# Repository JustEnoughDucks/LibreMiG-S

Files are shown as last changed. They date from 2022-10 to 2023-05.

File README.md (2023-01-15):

# LibreMiG-S

<!-- Improved compatibility of back to top link: See: https://github.com/othneildrew/Best-README-Template/pull/73 -->

<!--
*** Thanks for checking out the Best-README-Template. If you have a suggestion
*** that would make this better, please fork the repo and create a pull request
*** or simply open an issue with the tag "enhancement".
*** Don't forget to give the project a star!
*** Thanks again! Now go create something AMAZING! :D
-->

<!-- PROJECT SHIELDS -->
<!--
*** I'm using markdown "reference style" links for readability.
*** Reference links are enclosed in brackets [ ] instead of parentheses ( ).
*** See the bottom of this document for the declaration of the reference variables
*** for contributors-url, forks-url, etc. This is an optional, concise syntax you may use.
*** https://www.markdownguide.org/basic-syntax/#reference-style-links
-->
[][contributors-url]
[][forks-url]
[][stars-url]
[][issues-url]
[][license-url]
<!-- [![LinkedIn][linkedin-shield]][linkedin-url] -->

<!-- PROJECT LOGO -->
<br />
<div align="center">
  <a href="https://github.com/JustEnoughDucks/LibreMiG-S">
    
  </a>

  <h3 align="center">LibreMiG-S</h3>

  <p align="center">
    Open Source Joystick/Open Source Flightstick that combines the Olukelu Gimbal with a MiG-31 inspired Flightstick designed for Star Citizen or space simulators
    <!-- <br />
    <a href="https://github.com/JustEnoughDucks/LibreMiG-S"><strong>Explore the docs »</strong></a>
    <br /> -->
    <br /> 
    <a href="https://github.com/JustEnoughDucks/LibreMiG-S">View Demo</a>
    ·
    <a href="https://github.com/JustEnoughDucks/LibreMiG-S/issues">Report Bug</a>
    ·
    <a href="https://github.com/JustEnoughDucks/LibreMiG-S/issues">Request Feature</a>
  </p>
</div>

<!-- TABLE OF CONTENTS -->
<details>
  <summary>Table of Contents</summary>
  <ol>
    <li>
      <a href="#about-the-project">About The Project</a>
      <ul>
        <li><a href="#built-with">Built With</a></li>
      </ul>
    </li>
    <li>
      <a href="#getting-started">Getting Started</a>
      <ul>
        <li><a href="#prerequisites">Prerequisites</a></li>
        <li><a href="#installation">Installation</a></li>
      </ul>
    </li>
    <li><a href="#usage">Usage</a></li>
    <li><a href="#roadmap">Roadmap</a></li>
    <li><a href="#contributing">Contributing</a></li>
    <li><a href="#license">License</a></li>
    <li><a href="#contact">Contact</a></li>
    <li><a href="#acknowledgments">Acknowledgments</a></li>
  </ol>
</details>

<!-- ABOUT THE PROJECT -->
## About The Project

<!-- [![Product Name Screen Shot][product-screenshot]](https://example.com)-->

I saw few options for open-source flight sticks out there. Commercial options are exceedingly expensive. I strive to build a full-featured and high-quality Flightstick with a target BOM cost from 150-200€. It is not meant to be the cheapest joystick, but it does aim to be the most attractive option for open-source and DIY enthusiasts.

BOMs, parts lists, and documentation for various gimbals and 3D printed joysticks are sparse at best. I aim to include an extremely comprehensive requirements list, drop-in replacement part list, etc... so that this will be as accessible to everyone who has interest in building their own stick.

This is very open to all contributions and improvements from the community.

<p align="right">(<a href="#readme-top">back to top</a>)</p>

### Built With
<!--
* [![Next][Next.js]][Next-url]
* [![React][React.js]][React-url]
* [![Vue][Vue.js]][Vue-url]
* [![Angular][Angular.io]][Angular-url]
* [![Svelte][Svelte.dev]][Svelte-url]
* [![Laravel][Laravel.com]][Laravel-url]
* [![Bootstrap][Bootstrap.com]][Bootstrap-url]
* [![JQuery][JQuery.com]][JQuery-url]
-->
<p align="right">(<a href="#readme-top">back to top</a>)</p>

<!-- GETTING STARTED -->
## Getting Started

This process is hopefully as painless as possible. It will take hours of printing, some of soldering, assembling, and testing to make sure everything works. In order to have the most quality product as possible and respect the supply chain issues everyone has, I chose the cheapest, most available chip that is also easy to solder onto the PCB, but also has integrated USB so you don't need to search for an elusive USB HID FTDI chip. Everything can be assembled and disassembled repeatedly in principle (minimal/no direct screw to print interfaces)

I also added alternate electronics headers so that one can use an [STM32 Bluepill](https://microcontrollerslab.com/stm32f103c8t6-blue-pill-pinout-peripherals-programming-features/) in place of the USB, MCU, and power components if you don't like soldering. The upside to this is that I may be able to make a firmware profile compatible with FreeJoy in the future. I will have to look into compatibility with I2C peripherals in FreeJoy. If one is using the embedded MCU, then it will require the custom firmware. Everything should be plug-and-play with no drivers needed because proper USB descriptors will be developed.

### Prerequisites

This is a very general list of the materials you will need to assemble and program the stick. All BOM items are assumed to be ordered and received.

<!--  ```sh
  npm install npm@latest -g
  ```
-->
* 3D Printer
* Soldering Iron/Soldering Station + solder + flux paste/pen
* Microscope for soldering
* Hex key drivers and philips 0 screwdriver (dependent on your bolt choice)
* Mechanical and electrical BOM materials
* Manufactured PCBs
* ST-Link V2 or STM32F0 disovery board + jumpers for programming MCU
* USB-C cable
* PC running Linux or Windows
* STM32CubeProgrammer or PlatformIO on VSCode/Code-OSS
  
### Installation

<!-- 1. Get a free API Key at [https://example.com](https://example.com)
2. Clone the repo
   ```sh
   git clone https://github.com/github_username/repo_name.git
   ```
3. Install NPM packages
   ```sh
   npm install
   ```
4. Enter your API in `config.js`
   ```js
   const API_KEY = 'ENTER YOUR API';
   ```
-->
<p align="right">(<a href="#readme-top">back to top</a>)</p>

<!-- USAGE EXAMPLES -->
## Usage

<!-- Use this space to show useful examples of how a project can be used. Additional screenshots, code examples and demos work well in this space. You may also link to more resources.

_For more examples, please refer to the [Documentation](https://example.com)_ -->

<p align="right">(<a href="#readme-top">back to top</a>)</p>

<!-- ROADMAP -->
## Roadmap

- [X] 3D printed shells and parts designed
- [ ] 3D printed parts fully printable and assemblable
- [X] PCBs made in single panel and multi-board configurations
- [ ] Windows and Linux compatible firmware
    - [ ] Firmware can detect a TM/Virpil grip and fall back into "basic mode"
    - [ ] Drivers if needed
- [ ] Assembly Instructions
    - [ ] Video
- [ ] Button binding instructions
    - [ ] Video
- [ ] BOM for electronics
- [ ] BOM for mechanics
- [ ] Cost estimates for 1 american, 1 european, and 1 chinese manufacturers
- [ ] Documentation
- [ ] Possibly selling electronics kits or assembed kits?

See the [open issues](https://github.com/JustEnoughDucks/LibreMiG-S/issues) for a full list of proposed features (and known issues).

<p align="right">(<a href="#readme-top">back to top</a>)</p>

<!-- CONTRIBUTING -->
## Contributing

Contributions are what make the open source community such an amazing place to learn, inspire, and create. Any contributions you make are **greatly appreciated**.

If you have a suggestion that would make this better, please fork the repo and create a pull request. You can also simply open an issue with the tag "enhancement".
Don't forget to give the project a star! Thanks again!

1. Fork the Project
2. Create your Feature Branch (`git checkout -b feature/AmazingFeature`)
3. Commit your Changes (`git commit -m 'Add some AmazingFeature'`)
4. Push to the Branch (`git push origin feature/AmazingFeature`)
5. Open a Pull Request

<p align="right">(<a href="#readme-top">back to top</a>)</p>

<!-- LICENSE -->
## License

Distributed under the CERN-OHL-S-v2 License. See [`LICENSE`](https://github.com/JustEnoughDucks/LibreMiG-S/blob/main/LICENSE) for more information.

<p align="right">(<a href="#readme-top">back to top</a>)</p>

<!-- CONTACT -->
## Contact

<!-- Benjamin - [@twitter_handle](https://twitter.com/twitter_handle) - email@email_client.com -->

Project Link: [https://github.com/JustEnoughDucks/LibreMiG-S](https://github.com/JustEnoughDucks/LibreMiG-S)

<p align="right">(<a href="#readme-top">back to top</a>)</p>

<!-- ACKNOWLEDGMENTS -->
## Acknowledgments

* []()
* []()
* []()

<p align="right">(<a href="#readme-top">back to top</a>)</p>

<!-- MARKDOWN LINKS & IMAGES -->
<!-- https://www.markdownguide.org/basic-syntax/#reference-style-links -->
[contributors-shield]: https://img.shields.io/github/contributors/JustEnoughDucks/LibreMiG-S?style=for-the-badge
[contributors-url]: https://github.com/JustEnoughDucks/LibreMiG-S/graphs/contributors
[forks-shield]: https://img.shields.io/github/forks/JustEnoughDucks/LibreMiG-S?style=for-the-badge
[forks-url]: https://github.com/JustEnoughDucks/LibreMiG-S/network/members
[stars-shield]: https://img.shields.io/github/stars/JustEnoughDucks/LibreMiG-S?style=for-the-badge
[stars-url]: https://github.com/JustEnoughDucks/LibreMiG-S/stargazers
[issues-shield]: https://img.shields.io/github/issues/JustEnoughDucks/LibreMiG-S?style=for-the-badge
[issues-url]: https://github.com/JustEnoughDucks/LibreMiG-S/issues
[license-shield]: https://img.shields.io/badge/License-CERN--OHL--v2--S-brightgreen?style=for-the-badge
[license-url]: https://ohwr.org/cern_ohl_s_v2.pdf
[linkedin-shield]: https://img.shields.io/badge/-LinkedIn-black.svg?style=for-the-badge&logo=linkedin&colorB=555
[linkedin-url]: https://linkedin.com/in/linkedin_username
[product-screenshot]: images/screenshot.png
[Next.js]: https://img.shields.io/badge/next.js-000000?style=for-the-badge&logo=nextdotjs&logoColor=white
[Next-url]: https://nextjs.org/
[React.js]: https://img.shields.io/badge/React-20232A?style=for-the-badge&logo=react&logoColor=61DAFB
[React-url]: https://reactjs.org/
[Vue.js]: https://img.shields.io/badge/Vue.js-35495E?style=for-the-badge&logo=vuedotjs&logoColor=4FC08D
[Vue-url]: https://vuejs.org/
[Angular.io]: https://img.shields.io/badge/Angular-DD0031?style=for-the-badge&logo=angular&logoColor=white
[Angular-url]: https://angular.io/
[Svelte.dev]: https://img.shields.io/badge/Svelte-4A4A55?style=for-the-badge&logo=svelte&logoColor=FF3E00
[Svelte-url]: https://svelte.dev/
[Laravel.com]: https://img.shields.io/badge/Laravel-FF2D20?style=for-the-badge&logo=laravel&logoColor=white
[Laravel-url]: https://laravel.com
[Bootstrap.com]: https://img.shields.io/badge/Bootstrap-563D7C?style=for-the-badge&logo=bootstrap&logoColor=white
[Bootstrap-url]: https://getbootstrap.com
[JQuery.com]: https://img.shields.io/badge/jQuery-0769AD?style=for-the-badge&logo=jquery&logoColor=white
[JQuery-url]: https://jquery.com

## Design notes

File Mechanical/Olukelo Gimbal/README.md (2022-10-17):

# Olukelo Gimbal Files

These files are taken from a fork of the [Olukelu Gimbal](https://github.com/o-devices/o-joystick-hdk) by [Scrath1](https://github.com/Scrath1/o-joystick-hdk)
which has the benefit of including re-exported STEP files.

These files are necessary to print for the entire gimbal base to attach the joystick too. There will be a BOM section that specifies all of the correct
bolt heads and sizings as well as recommended springs to use on the gimbal.

### Instructions
All files are in their correct orientation by default (when tested with Prusa Slicer 2.5). There is an alternate housing that will be added later that
integrates the microcontroller board and some useful buttons and switches for people that don't have a separate button box (or do, but want more buttons).

The gimbal_cam.stl (4 pieces) should be printed out of PLA for low deformation. The gimbal itself can be printed of PET, PETG, ABS, or possibly nylon. I have tested it with
FormFutura recycled PET and it has good flexibility and enough rigidity. I will perhaps do some later testing on how to PLA holds up for the cams. 

### License Considerations
I did not create, modify, or remix these files, they are only being distributed in order to have a repository of a full, working set of 3D files in case the
Olukelu files get lost somehow. These files fall under the [CC BY-NC-SA 4.0](https://creativecommons.org/licenses/by-nc-sa/4.0/) license according to the original
Thingiverse [source](https://www.thingiverse.com/thing:2496028).

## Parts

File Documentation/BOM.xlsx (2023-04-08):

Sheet: Electrical
PCB LibreMig-S
Designator | Footprint | Quantity | Value | LCSC | Manufacturer | MPN | Supplier 1 | Supplier 2 | Alternate MPN
C1, C10, C14, C15, C16, C19, C20, C21, C22, C23, C24, C26, C27, C28, C29, C30, C31, C32, C5, C6, C7, C8 | C_0805_2012Metric | 22 | 100nF
C11 | C_0805_2012Metric | 1 | 10nF
C12, C13 | C_0805_2012Metric | 2 | 1uF |  | Kemet | C0805C105K9RACTU
C17, C18 | C_0603_1608Metric | 2 | 27pF
C25, C33, C34, C35, C36, C37, C38, C39, C40, C41, C42, C43, C46, C47 | C_0603_1608Metric | 14 | 100nF
C4, C9 | C_0805_2012Metric | 2 | 4.7uF
C44, C45 | C_0603_1608Metric | 2 | 10nF
D1, D2 | D_SOD-923 | 3 | ESD9B3.3ST5G |  | Murata | ESD9B3.3ST5G | Mouser
D3 | D_SOD-923 |  | ESD9B5.0ST5G |  | Murata | ESD9B5.0ST5G | Mouser
D4, D5 | LED_0603_1608Metric_Pad1.05x0.95mm_HandSolder | 2 | LED
FB1, FB2 | C_0603_1608Metric | 2 | BLM18BA470SZ1D |  | onsemi | BLM18BA470SZ1D | Mouser
J1, J13 | JST_PH_B5B-PH-K_1x05_P2.00mm_Vertical | 2 | Conn_01x05 |  | JST | JST_PH_B5B-PH-K | Conrad
J10, J14, J2, J20, J23, J3, J8, J9 | JST_PH_B3B-PH-K_1x03_P2.00mm_Vertical | 8 | Conn_01x03 |  | JST | JST_PH_B3B-PH-K | Conrad
J11, J19 | JST_PH_S8B-PH-K_1x08_P2.00mm_Horizontal | 2 | Conn_01x08 |  | JST | JST_PH_S8B-PH-K | Conrad
J12, J21 | JST_PH_B8B-PH-K_1x08_P2.00mm_Vertical | 2 | Conn_01x08 |  | JST | JST_PH_B8B-PH-K | Conrad
J15 | JST_PH_B6B-PH-K_1x06_P2.00mm_Vertical | 1 | Conn_01x06 |  | JST | JST_PH_B6B-PH-K | Conrad
J16 | JST_PH_B2B-PH-K_1x02_P2.00mm_Vertical | 1 | Conn_01x02 |  | JST | JST_PH_B2B-PH-K | Conrad
J17 | JST_PH_S6B-PH-K_1x06_P2.00mm_Horizontal | 1 | Conn_01x06 |  | JST | JST_PH_S6B-PH-K | Conrad
J18 | JST_PH_S3B-PH-K_1x03_P2.00mm_Horizontal | 1 | Conn_01x03 |  | JST | JST_PH_S3B-PH-K | Conrad
J24 | USB_C_Receptacle_HRO_TYPE-C-31-M-12 | 1 | USB_C_Receptacle_USB2.0 |  | Molex | 217179-0001 | Mouser
J4, J5 | JST_PH_S5B-PH-K_1x05_P2.00mm_Horizontal | 2 | Conn_01x05 |  | JST |  | Conrad
J6, J7 | PinSocket_1x20_P2.54mm_Vertical | 2 | Conn_01x20
R10 | R_0603_1608Metric | 1 | 250
R15, R16, R17, R18, R32, R33, R34, R35, R40, R41, R42, R43 | R_0603_1608Metric | 12 | 4.7k
R23, R24, R36, R37, R44, R45 | R_0603_1608Metric | 6 | 100k
R25, R26, R38, R39, R46, R47 | R_0603_1608Metric | 6 | 110k
R27, R28 | R_0603_1608Metric | 2 | 620
R29 | C_0805_2012Metric | 1 | 10k
R3, R4, R7, R8, R9 | R_0805_2012Metric | 5 | 10k
R30 | R_0805_2012Metric | 1 | R
R31 | R_0805_2012Metric_Pad1.20x1.40mm_HandSolder | 1 | R
R5, R6 | R_0805_2012Metric | 2 | 5.6k
RN1, RN2, RN3, RN4, RN5, RN6 | R_Array_SIP6 | 6 | 10k |  | Bourns | 4606X-101-103LF | Mouser
SW1, SW2, SW3 | SW_PUSH-12mm_Wuerth-430476085716 | 3 | SW_Push |  | Omron Electronics | B3F-4055 | Mouser
SW10, SW11, SW12, SW13, SW8, SW9 | SW_Cherry_MX_1.00u_PCB | 6 | SW_Push |  | Cherry | MX1A-G1NW | Mouser
SW14 | KC14A10.001NPS | 1 | SW_Coded |  | E-switch | KC14A10.001NPS | Mouser
SW15 | RKJXT1F | 1 | RKJXV1220 |  | Alps | RKJXT1F42001 | Mouser
SW16 | PS1024AL | 1 | SW_Push |  | E-switch | PS1024ALRED | Mouser
SW18 | SKRHABE010 | 1 | SKRHABE010 |  | Alps | SKRHABE010 | Mouser
SW4 | SW_PUSH_6mm | 1 | SW_Push |  | Generic | Generic | Mouser
SW5, SW6, SW7 | PinHeader_1x03_P2.54mm_Vertical | 3 | SW_SPDT |  | Mountain Switch | 10TC610 | Mouser
U1 | LQFP-48_7x7mm_P0.5mm | 1 | STM32F072CBTx |  | STM | STM32F072CBTx | Mouser | Sinuss.be
U2, U3 | TSSOP-24_4.4x7.8mm_P0.65mm | 2 | TCA9535PWR |  | TI | TCA9535PWR | Mouser | RS Components
U4, U7 | TSSOP-14_4.4x5mm_P0.65mm | 2 | MCP6004 |  | Microchip | MCP6004 | Mouser
U5 | TSOT-23-5 | 1 | ADP122AUJZ-3.3-R7 |  | Analog Devices | ADP122AUJZ-3.3-R7 | Mouser
U6 | MSOP-8_3x3mm_P0.65mm | 1 | MAX11613 |  | Maxim Integrated | MAX11613 | Mouser
VR1 | RKJXV1220 | 1 | Joystick_Pot |  | Alps | RKJXV1220 | Mouser
Y1 | Crystal_HC49-4H_Vertical | 1 | ABL-8.000MHZ-B2 |  | Abrocon | ABL-8.000MHZ-B2 | Mouser
Non-PCB Electronics
Description |  | Quantity |  |  | Manufacturer | MPN | Supplier 1 | Supplier 2 | Alternate MPN
Mini-DIN 5p fack, female, 100mm wire |  | 1 |  |  | CUI Devices | MD-50PL100 | Mouser
Mini-DIN 5p fack, male, assembly required |  | 1 |  |  | Kycon | KMDLAX-5P | Mouser
Linear Hall Effect Sensor |  | 4 |  |  | Diodes Incorporated | AH49HZ3-G1 | Mouser
Assorted wire colors, stranded 24 AWG/ 0.2mm^2 wire |  | 60m |  |  | Velleman | K/MOW | Sinuss/Farnell
JST PH Crimp Terminals |  | 83 |  |  | JST | JST BPH-002T-P0.5S | Conrad |  | JST SPH-002T-P0.5S
JST PH 2p housing |  | 1 |  |  | JST | JST PHR-2 | Conrad
JST PH 3p housing |  | 9 |  |  | JST | JST PHR-3 | Conrad
JST PH 5p housing |  | 2 |  |  | JST | JST PHR-5 | Conrad
JST PH 6p housing |  | 2 |  |  | JST | JST PHR-6 | Conrad
JST PH 8p housing |  | 4 |  |  | JST | JST PHR-8 | Conrad
6mm Push button (>250g actuation force, best) |  | 5 |  |  | Generic | Generic
USB-C cable to USB-A |  | 1 |  |  | Generic | Generic | Anywhere

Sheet: Mechanical
Mechanical Parts
Description | Quantity | Manufacturer | MPN | Supplier 1 | Supplier 2 | Alternate MPN
17x30x9 ID/OD/H Thrust Bearing | 1 | UBC | 51103 | Conrad | Nieta
15x24x5 ID/OD/H Ball Bearing | 4 | Generic | 6802 ZZ | Ebay – kugellager-handloser | Nieta | 61802 2Z
5x10x4 ID/OD/H Ball Bearing with flange | 8 | Generic | MF105 ZZ | Ebay – kugellager-handloser | Nieta
5x11x5 ID/OD/H Ball Bearing | 4 | Generic | 685 ZZ | Ebay – kugellager-handloser | Nieta | 638/5 2Z
M3 Bolt x
M3 Bolt x
M3 Bolt x
M3 Bolt x
M4 Bolt x
M5 Bolt x

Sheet: Equipment
Suggested Equipment
Description | Optional | Manufacturer | MPN | Supplier 1 | Alt MPN
Soldering Iron | N
Lead-Free Solder (SN99.3 Cu 0.7 for example) | N | Broquetas | ELE-LF100-05 | Eleshop.eu
Solder Flux | N
Brass Wool | Y
Tweezers | N
Wire Stripper | N | Weicon | 51000005 | Eleshop.eu
JST-capable wire crimper | N | Adafruit | 350 |  | PA-09
ST-Link v2 | Y
Soldering Microscope/Magnifier | Y
Hex key drivers | N
Philips 0 screwdriver | N
PC running Linux or Windows | N |  |  | N/A
STM32CubeProgrammer or PlatformIO | N |  |  | N/A
3D Printer |  | Prusa | Prusa Mk3 |  | Prusa Mk4

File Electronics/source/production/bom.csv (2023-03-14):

Designator | Footprint | Quantity | Value | LCSC Part #
_105, _104, _103, _102, _101, _100, _99, _98, _97, _96, _95, _94, _93, _92, _91, _90, _89, _88, _87, _86, _85, _84, _83, _82, _81, _80, _79, _78, _77, _76, _75, _74, _73, _72, _71, _70, _69, _68, _67, _66, _65, _64, _63, _62, _61, _60, _59, _58, _57, _56, _55, _54, _53, _52, _51, _50, _49, _48, _47, _46, _45, _44, _43, _42, _41, _40, _39, _38, _37, _36, _35, _34, _33, _32, _31, _30, _29, _28, _27, _26, _25, _24, _23, _22, _21, _20, _19, _18, _17, _16, _15, _14, _13, _12, _11, _10, _9, _8, _7, _6, _5, _4, _3, _2, |  | 105
C1, C10, C14, C15, C16, C19, C20, C21, C22, C23, C24, C26, C27, C28, C29, C30, C31, C32, C5, C6, C7, C8 | C_0805_2012Metric | 22 | 100nF
C11 | C_0805_2012Metric | 1 | 10nF
C12, C13 | C_0805_2012Metric | 2 | 1uF
C17, C18 | C_0603_1608Metric | 2 | 27pF
C25, C33, C34, C35, C36, C37, C38, C39, C40, C41, C42, C43, C46, C47 | C_0603_1608Metric | 14 | 100nF
C4, C9 | C_0805_2012Metric | 2 | 4.7uF
C44, C45 | C_0603_1608Metric | 2 | 10nF
D1, D2, D3 | D_SOD-923 | 3 | ESD9B5.0ST5G
D4, D5 | LED_0603_1608Metric_Pad1.05x0.95mm_HandSolder | 2 | LED
FB1, FB2 | C_0603_1608Metric | 2 | BLM18BA470SZ1D
J1, J13 | JST_PH_B5B-PH-K_1x05_P2.00mm_Vertical | 2 | Conn_01x05
J10, J14, J2, J20, J23, J3, J8, J9 | JST_PH_B3B-PH-K_1x03_P2.00mm_Vertical | 8 | Conn_01x03
J11, J19 | JST_PH_S8B-PH-K_1x08_P2.00mm_Horizontal | 2 | Conn_01x08
J12, J21 | JST_PH_B8B-PH-K_1x08_P2.00mm_Vertical | 2 | Conn_01x08
J15 | JST_PH_B6B-PH-K_1x06_P2.00mm_Vertical | 1 | Conn_01x06
J16 | JST_PH_B2B-PH-K_1x02_P2.00mm_Vertical | 1 | Conn_01x02
J17 | JST_PH_S6B-PH-K_1x06_P2.00mm_Horizontal | 1 | Conn_01x06
J18 | JST_PH_S3B-PH-K_1x03_P2.00mm_Horizontal | 1 | Conn_01x03
J22 | PinHeader_1x04_P2.54mm_Vertical | 1 | Conn_01x04
J24 | USB_C_Receptacle_HRO_TYPE-C-31-M-12 | 1 | USB_C_Receptacle_USB2.0
J25 | Tag-Connect_TC2030-IDC-NL_2x03_P1.27mm_Vertical | 1 | Conn_01x06
J4, J5 | JST_PH_S5B-PH-K_1x05_P2.00mm_Horizontal | 2 | Conn_01x05
J6, J7 | PinSocket_1x20_P2.54mm_Vertical | 2 | Conn_01x20
JP1, JP2 | SolderJumper-2_P1.3mm_Open_TrianglePad1.0x1.5mm | 2 | Jumper_2_Open
R10 | R_0603_1608Metric | 1 | 250
R15, R16, R17, R18, R32, R33, R34, R35, R40, R41, R42, R43 | R_0603_1608Metric | 12 | 4.7k
R23, R24, R36, R37, R44, R45 | R_0603_1608Metric | 6 | 100k
R25, R26, R38, R39, R46, R47 | R_0603_1608Metric | 6 | 110k
R27, R28 | R_0603_1608Metric | 2 | 620
R29 | C_0805_2012Metric | 1 | 10k
R3, R4, R7, R8, R9 | R_0805_2012Metric | 5 | 10k
R30 | R_0805_2012Metric | 1 | R
R31 | R_0805_2012Metric_Pad1.20x1.40mm_HandSolder | 1 | R
R5, R6 | R_0805_2012Metric | 2 | 5.6k
RN1, RN2, RN3, RN4, RN5, RN6 | R_Array_SIP6 | 6 | 10k
SW1, SW2, SW3 | SW_PUSH-12mm_Wuerth-430476085716 | 3 | SW_Push
SW10, SW11, SW12, SW13, SW8, SW9 | SW_Cherry_MX_1.00u_PCB | 6 | SW_Push
SW14 | KC14A10.001NPS | 1 | SW_Coded
SW15 | RKJXT1F | 1 | RKJXV1220
SW16 | PS1024AL | 1 | SW_Push
SW18 | SKRHABE010 | 1 | SKRHABE010
SW4 | SW_PUSH_6mm | 1 | SW_Push
SW5, SW6, SW7 | PinHeader_1x03_P2.54mm_Vertical | 3 | SW_SPDT
TP1, TP2 | TestPoint_Pad_D1.0mm | 2 | TestPoint
TP3, TP4, TP5, TP6, TP7, TP8 | TestPoint_Loop_D1.80mm_Drill1.0mm_Beaded | 6 | TestPoint
U1 | LQFP-48_7x7mm_P0.5mm | 1 | STM32F072CBTx
U2, U3 | TSSOP-24_4.4x7.8mm_P0.65mm | 2 | TCA9535PWR
U4, U7 | TSSOP-14_4.4x5mm_P0.65mm | 2 | MCP6004
U5 | TSOT-23-5 | 1 | ADP122AUJZ-3.3-R7
U6 | MSOP-8_3x3mm_P0.65mm | 1 | MAX11613
VR1 | RKJXV1220 | 1 | Joystick_Pot
Y1 | Crystal_HC49-4H_Vertical | 1 | ABL-8.000MHZ-B2
mouse-bite-5mm-slot_5, mouse-bite-5mm-slot_4, mouse-bite-5mm-slot_3, mouse-bite-5mm-slot_2, mouse-bite-5mm-slot | mouse-bite-5mm-slot | 5 | VAL**

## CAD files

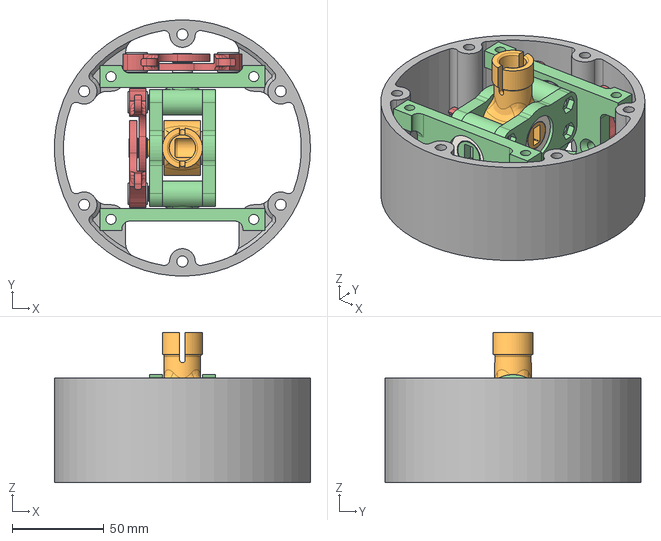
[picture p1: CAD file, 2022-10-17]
Mechanical/Olukelo Gimbal/gimbal_frame_assembly.step
139.9 x 139.9 x 82.0 mm

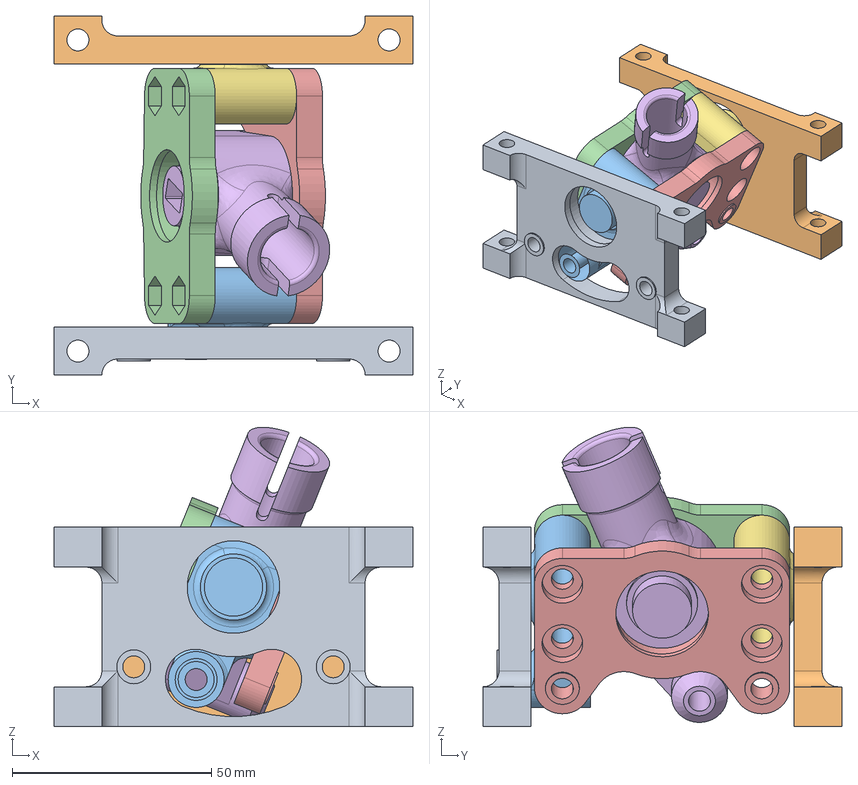
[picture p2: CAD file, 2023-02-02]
Mechanical/source/enclosure_assembly.FCStd
90.0 x 90.0 x 75.0 mm
frame_back001
frame_front001
gimbal_back
gimbal_right
gimbal_left
gimbal_stem
gimbal_front

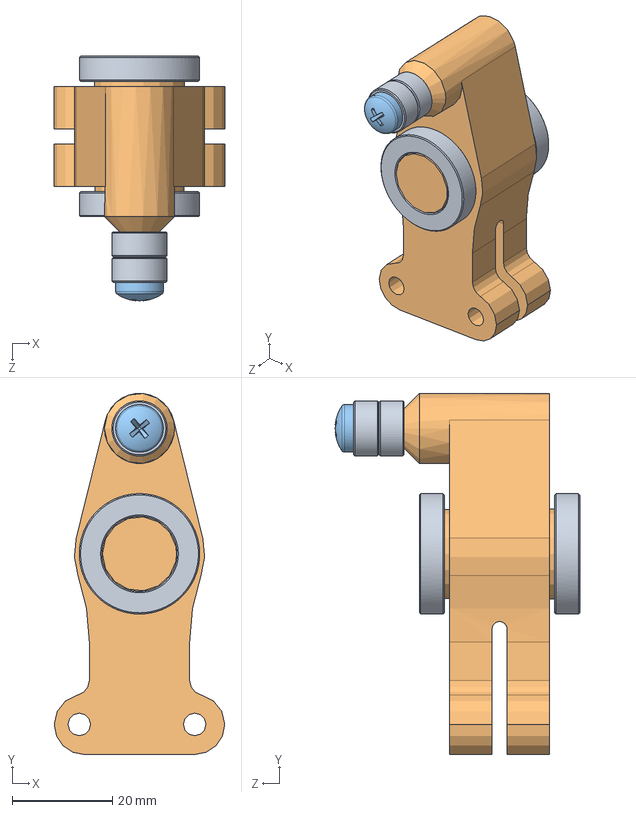
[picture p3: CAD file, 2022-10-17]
Mechanical/Olukelo Gimbal/solidwork/gimbal_lever_arm_assembly.SLDASM
34.0 x 72.0 x 48.8 mm
Bearing x 4
gimbal_lever_arm
pan cross head_am

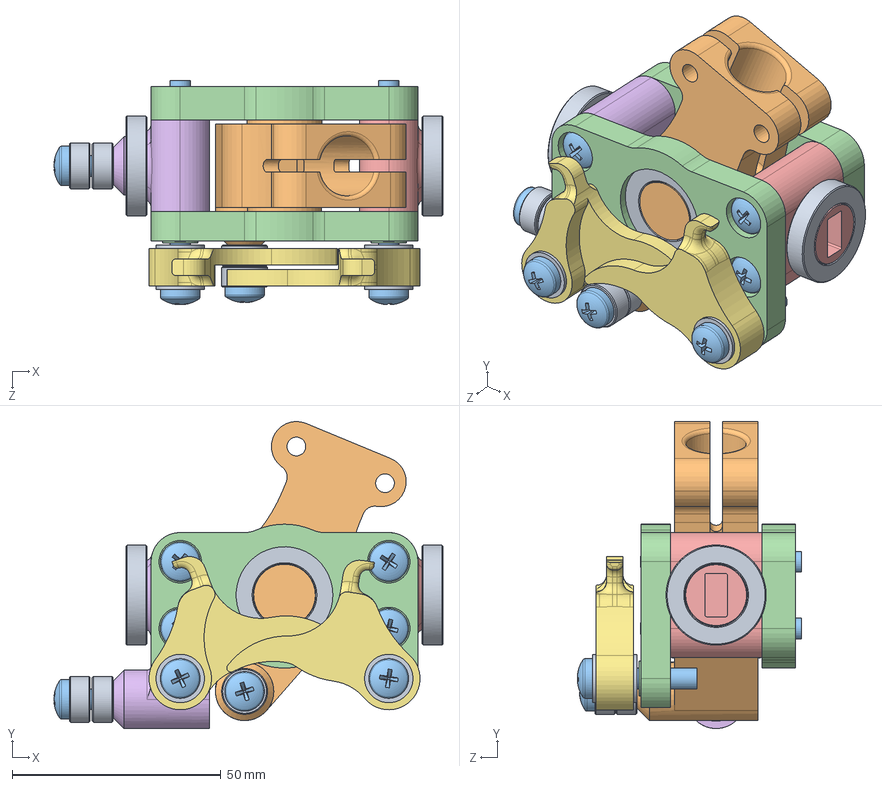
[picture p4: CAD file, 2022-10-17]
Mechanical/Olukelo Gimbal/solidwork/gimbal_core_assembly.SLDASM
93.3 x 73.6 x 53.8 mm
Bearing x 12
gimbal_lever_arm
pan cross head_am x 8
gimbal_core_bearing_carrier x 2
gimbal_core_pot_side
gimbal_core_non_pot_side
gimbal_cam x 2
hex nut jam_am x 5

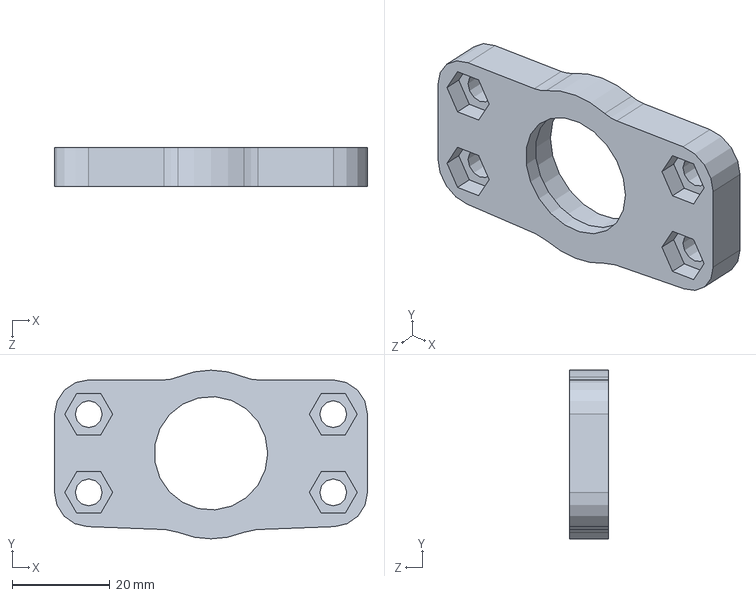
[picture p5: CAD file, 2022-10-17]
Mechanical/Olukelo Gimbal/solidwork/gimbal_core_bearing_carrier.SLDPRT
64.0 x 34.5 x 8.00 mm

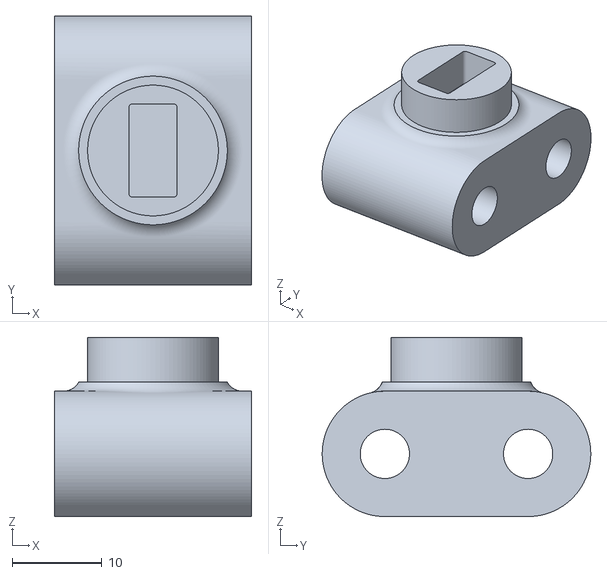
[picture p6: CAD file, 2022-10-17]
Mechanical/Olukelo Gimbal/stl/gimbal_core_pot_side.STL
22.0 x 30.0 x 20.0

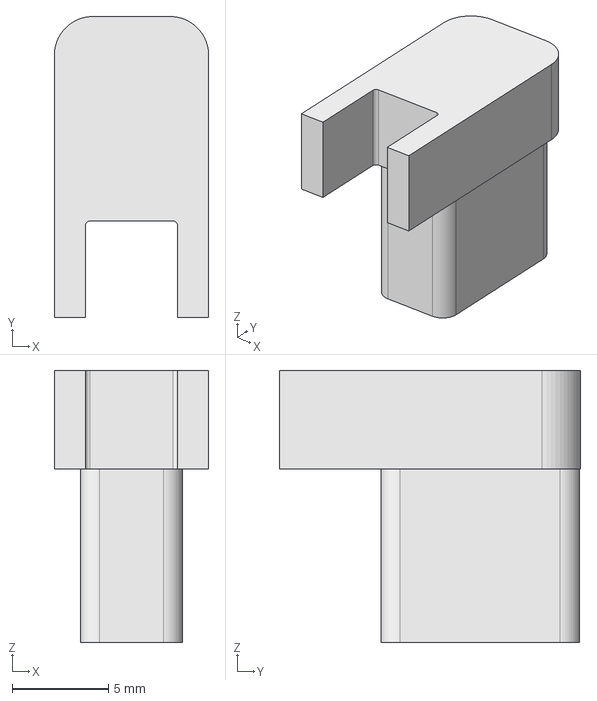
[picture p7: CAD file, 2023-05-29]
Mechanical/source/assembly/Magnet Insert Gimbal.FCStd
8.00 x 15.6 x 14.1 mm

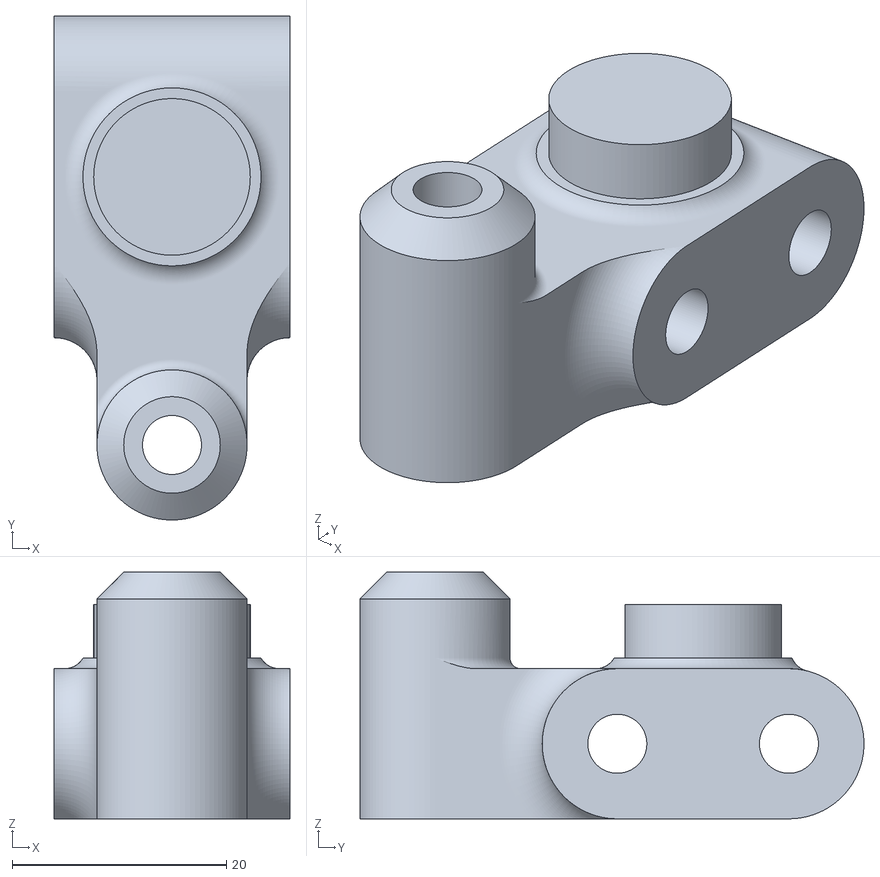
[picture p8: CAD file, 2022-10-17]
Mechanical/Olukelo Gimbal/stl/gimbal_core_non_pot_side.STL
22.0 x 47.0 x 23.0

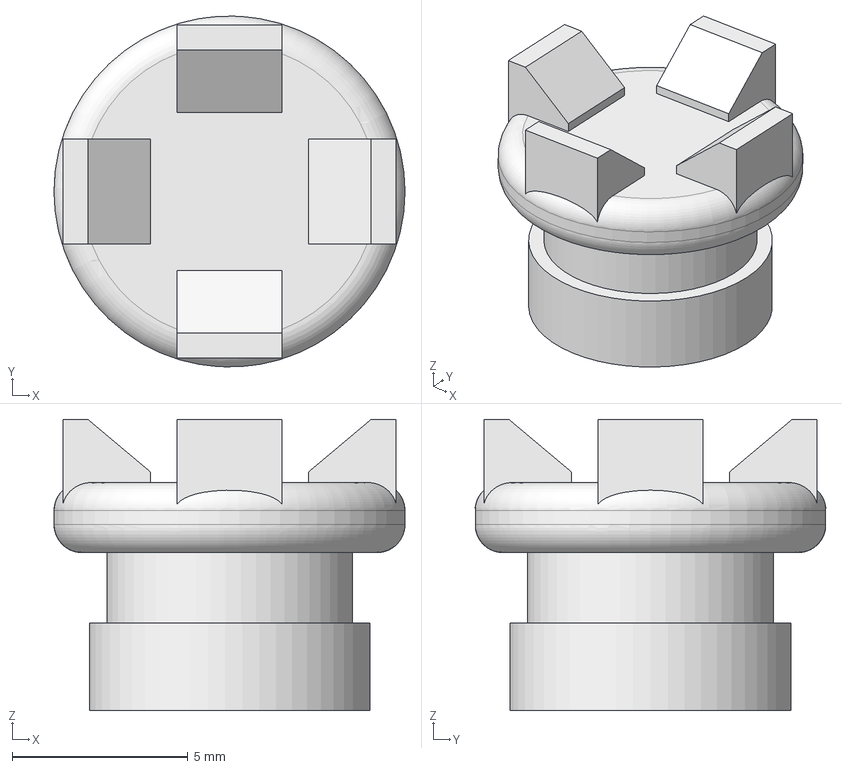
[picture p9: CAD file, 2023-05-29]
Mechanical/source/assembly/thumbsticks.FCStd
10.0 x 9.99 x 8.30 mm

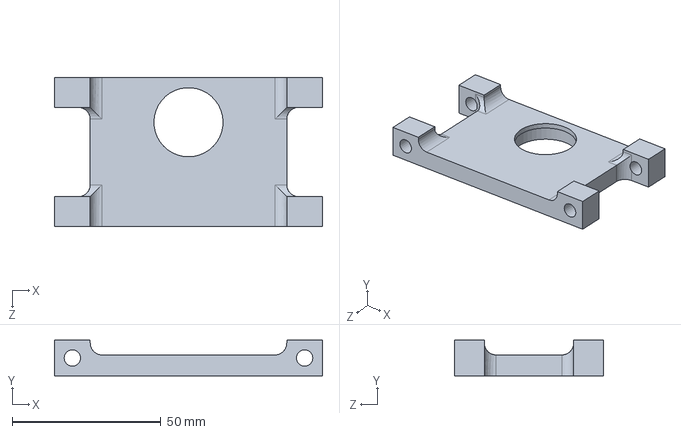
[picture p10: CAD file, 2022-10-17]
Mechanical/Olukelo Gimbal/solidwork/gimbal_frame.SLDPRT
90.0 x 12.0 x 50.0 mm

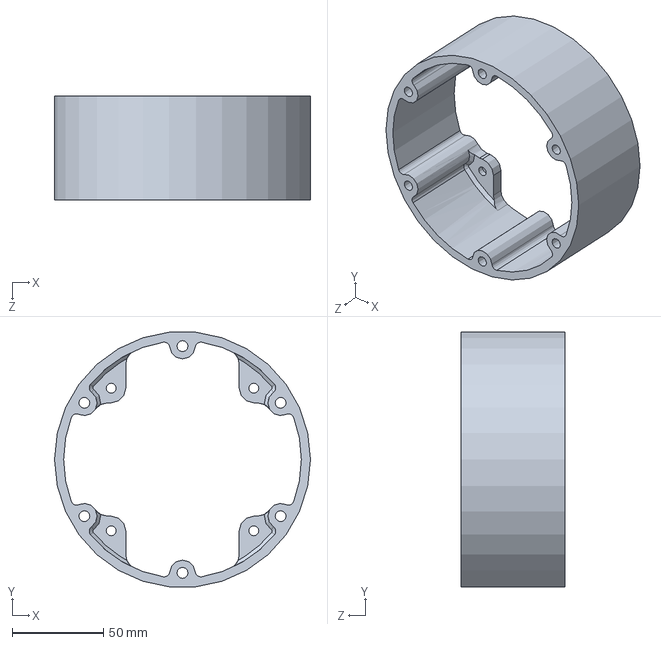
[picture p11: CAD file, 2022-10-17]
Mechanical/Olukelo Gimbal/solidwork/housing_body.SLDPRT
140.0 x 139.2 x 57.0 mm

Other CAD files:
Mechanical/source/stick_assembly.FCStd
Mechanical/source/assembly/flip assembly.FCStd
Mechanical/Olukelo Gimbal/solidwork/gimbal_frame_assembly.SLDASM
Electronics/source/libre-MIG.dxf
Mechanical/Olukelo Gimbal/solidwork/gimbal_core_pot_side.SLDPRT
Mechanical/Olukelo Gimbal/stl/gimbal_frame_cam_side.STL
Mechanical/source/board_panel_shape.FCStd
Mechanical/Olukelo Gimbal/solidwork/Bearing.SLDPRT
Mechanical/Olukelo Gimbal/solidwork/gimbal_cam.SLDPRT
Mechanical/Olukelo Gimbal/solidwork/gimbal_core_non_pot_side.SLDPRT
Mechanical/Olukelo Gimbal/solidwork/gimbal_lever_arm.SLDPRT
Mechanical/Olukelo Gimbal/stl/gimbal_cam.STL
Mechanical/Olukelo Gimbal/stl/gimbal_core_bearing_carrier_non_pot_side.STL
Mechanical/Olukelo Gimbal/stl/gimbal_core_bearing_carrier_pot_side.STL
Mechanical/Olukelo Gimbal/stl/gimbal_frame_pot_side.STL
Mechanical/Olukelo Gimbal/stl/gimbal_lever_arm.STL
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

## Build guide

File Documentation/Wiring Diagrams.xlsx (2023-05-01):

MINI DIN 5p Base to Grip Connectors
 | Color | MD-50PL100 | Function | KMDLAX-5P | Color
 | Red | 1 | GND | 1 | Red
 | Green | 2 | SCL | 2 | Green
 | Brown | 3 | VCC | 3 | Brown
 | Black | 4 | EN | 4 | Black
 | Yellow | 5 | SDA | 5 | Yellow
 | Mini DIN 5p to JST-PHR (Base & Grip)
 | Color | DIN 5p | Function | JST-PHR-5 | Color
 | Red | 1 | GND | 4 | Red
 | Green | 2 | SCL | 3 | Green
 | Brown | 3 | VCC | 1 | Brown
 | Black | 4 | EN | 5 | Black
 | Yellow | 5 | SDA | 2 | Yellow
 | JST-PHR-3 to Hall Effect Sensor
 | Color | JST-PHR-3 | Function | AH49H | Color
 | Red | 1 | VCC | 1 | Red
 | Black | 3 | GND | 2 | Black
 | Yellow | 2 | OUT | 3 | Yellow
 | JST-PHR-8 to Faceplate
 | Color | JST-PHR-8 | Function | JST-PHR-8 | Color
 | Red | 1 | Axis1 | 8 | Brown
 | Orange | 2 | Axis2 | 7 | Black
 | Yellow | 3 | Center | 6 | Purple
 | Green | 4 | DirC | 5 | Blue | rj
 | Blue | 5 | DirL | 4 | Green
 | Purple | 6 | DirR | 3 | Yellow
 | Black | 7 | DirU | 2 | Orange
 | Brown | 8 | DirD | 1 | Red
 | JST-PHR-8 to Thumbstick
 | Color | JST-PHR-8 | Function | JST-PHR-8 | Color
 | Black | 1 | Encode A | 1 | Black
 | White | 2 | DirU | 2 | White
 | Red | 3 | VCC | 3 | Red
 | Yellow | 4 | DirR | 4 | Yellow
 | Green | 5 | DirC | 5 | Green
 | Blue | 6 | DirL | 6 | Blue
 | Purple | 7 | DirD | 7 | Purple
 | Brown | 8 | Encode B | 8 | Brown
 |  | wire length = 46mm +/-4mm
 | JST-PHR-3 to Faceplate
 | Color | JST-PHR-3 | Function | AH49H | Color
 | Red | 1 | VCC | 3 | Red
 | Black | 3 | GND | 1 | Black
 | Yellow | 2 | Red Button | 2 | Yellow

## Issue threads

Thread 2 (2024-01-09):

compatibility with the OS-VBS MKII project

RightRudderLeftStick, 2024-01-09:
Hi, just came across this project on reddit, is it still under development?

I wonder if you'd consider compatibility with my project:
https://github.com/RightRudderLeftStick/OpenSource-VeryBigStick

It's CC BY-SA 2.0, and the only real requirement is for the stick to mount on the end of 2020 extrusion directly.

JustEnoughDucks, 2024-03-06:
Hey, I ended moving and started a full renovation, so it kind of dropped by the side as my 3D printer is unavailable for another year. My final full assembly build is still sitting in a box. I will see if I can restart it soon

I will definitely consider adding it. From what I can see of your project, it is just mechanical right now, correct? The issue I see right now is wire paths for bridging sensor to grip. That is difficult while using aluminum extrusions.

This stick uses the TM interface, so it should work with your stick on your already made extrusion-to-TM adapter, if I am not mistaken. Going to the [mechanical source files: ](https://github.com/JustEnoughDucks/LibreMiG-S/tree/8a1e5ddca9180a5b205c3cc3732c93596d07cc1f/Mechanical/source/assembly) and looking at the TM adapter and TM screw, you should be able to open them in FreeCAD and export it to STEP to fit it with your design in F360.

Maybe the most interesting for you will be when I do an electronics redesign with a mini PCB as the base controller along with a more robust I2C interface. I would be open to working together if you need electronics work done or want to make the systems cross-compatible.

RightRudderLeftStick, 2024-03-06:
Funny that you mention TM, I am right now working on a freejoy/mmjoy2/arduino breakout board and the stick will interface over the CD4021 connection:

https://www.patreon.com/posts/working-on-pcb-99781394

The sensors will be those TLE5010 kits on aliexpress since they are ready made. ( https://www.aliexpress.com/item/4000549883214.html )

JustEnoughDucks, 2024-03-06:
Yeah as I got into it, I realized that electrically matching TM's SPI/SSC/shift register interfaces leaves little flexibility because you are limited by chip select wires. I2C, while slower (for HID usecase still faster than USB can poll), allows for modularity and adding or removing more sensors with different stick iterations.

As far as the TLE5010 kits, since sensors on sticks never are 2 axis like a joystick and don't make full rotations, better accuracy and precision can be achieved with linear hall effect sensors, good mechanical design, and a good ADC. those angular sensors, you might only end up using 10 bits of the 16 bit conversion as an example since you only use a few degrees of its range for things like triggers or twist. Either one you choose, linear or all-in-one angular, a custom solution is going to be the easiest to get working reliably is fully custom (in the end), but the downside is that then you have to sell kits because most people won't want to solder a whole board themselves or have the equipment to do so.

RightRudderLeftStick, 2024-04-15:
Yeah wanted to keep stuff as much "off the shelf" as possible, thus sticking to the aliexpress TLE5010 kits for now.

btw just dropped a big update for the project with an electrical guide using MMJOY2 and a custom breakout board. I am going to follow up with a bluepill based breakout board next.

https://github.com/RightRudderLeftStick/OpenSource-VeryBigStick

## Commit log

2022-10-17 added reference Olukelu gimbal files from Scrath1
    [Bearing.SLDPRT, gimbal_cam.SLDPRT, gimbal_cam.STL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]
2022-10-17 updated directory structure
    [Bearing.SLDPRT, gimbal_cam.SLDPRT, gimbal_cam.STL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]
2022-10-22 Added source files for Mechanical partts
    [Brake Lever.FCStd, Flip Plank.FCStd, Flip Trigger.FCStd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]
2022-10-23 Added working schematics document
    [IO_controller.kicad_sch, MCU.kicad_sch, USB.kicad_sch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]
2022-10-27 started layout and finished board shapes
2022-10-29 Finished first layout of all boards
    [IO_controller.kicad_sch, MCU.kicad_sch, libre-MIG.kicad_pcb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]
2022-11-07 added mechanical ignore
    [USB.kicad_sch, libre-MIG.kicad_pcb, libre-MIG.kicad_sch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]
2022-11-09 Made PCB manufacturable and finished *-rounded silk
    [MCU.kicad_sch, board_panel_shape.FCStd, bom.csv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]
2022-11-11 finished rev0.1 of PCBs
    [MCU.kicad_sch, bom.csv, designators.csv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]
2022-12-05 Changed MCU to STM32F072 variant with built-in USB and removed wrong FTDI chip
    [MCU.kicad_sch, libre-MIG.kicad_sch, libre-MiG USB.kicad_pcb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]
2022-12-05 Polished some parts, refactored broken Shell, made enclosure sans bottom
    [Brake Lever.FCStd, Flip Plank.FCStd, Flip Trigger.FCStd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]
2022-12-29 small changes to make the model better printable, & refactoring
2022-12-29 small bug fixes and clock stability
    [MCU.kicad_sch, USB.kicad_sch, libre-MIG.kicad_pcb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]
2023-01-15 added firmware submodule to firmware repo
    [IO_controller.kicad_sch, MCU.kicad_sch, encoder.kicad_sch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]
2023-01-15 Added quick logo
    [MCU.kicad_sch, libre-MIG.kicad_pcb, libre-MIG.kicad_sch]
2023-01-15 Added amplifiers to utilize the full 12 bit ADC range from simple ~1.8V, .9V biased Hall effect sensors
2023-01-19 corrected incomplete USB for flipable cable, and replaced termination resistors w jumpers
    [MCU.kicad_sch, USB.kicad_sch, libre-MIG.kicad_pcb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]
2023-02-02 changed tolerances according to printed test
    [Flip Trigger.FCStd, enclosure_assembly.FCStd, flip assembly.FCStd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]
2023-02-12 implemented MCP6004/9 and rerouted
    [IO_controller.kicad_sch, MCU.kicad_sch, libre-MIG.kicad_pcb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]
2023-02-26 Redefined face shape to fit panel mount hat; rerouted; DRC check
    [MCU.kicad_sch, face_plate.kicad_sch, libre-MIG.kicad_pcb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]
2023-03-14 Rev 2 of electronics, full project fabrication outputs
    [bom.csv, designators.csv, encoder.kicad_sch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]
2023-04-08 Slowly adding cable wiring diagrams
    [Wiring Diagrams.xlsx]
2023-04-08 started on comprehensive BOM
    [BOM.xlsx]
2023-04-08 started comprehensive BOM
    [BOM.xlsx]
2023-04-08 fixed duplicate BOM
    [BOM.xlsx]
2023-05-01 updated wiring diagrams
    [Wiring Diagrams.xlsx]
2023-05-06 Corrected encoder code
2023-05-23 added change for a mechanical panel to insert brake hall effect sensor, model takes very long to open now
2023-05-27 Changed hole tolerances, added brake cover, removed assembly LCSs for now
2023-05-27 added thumbstick models and magnet holding jig
    [Magnet Insert Gimbal.FCStd, thumbsticks.FCStd]
2023-05-29 sunk PCB 2mm inward to account for selector switch standoffs, mechanics tentatively done
